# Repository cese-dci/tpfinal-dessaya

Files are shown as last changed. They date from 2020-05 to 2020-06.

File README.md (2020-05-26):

# Teensy 3.2

TP final de la materia Diseño de Circuitos Impresos - CESE - 2020A

Objetivo: Réplica del módulo [Teensy 3.2](https://www.pjrc.com/store/teensy32.html)








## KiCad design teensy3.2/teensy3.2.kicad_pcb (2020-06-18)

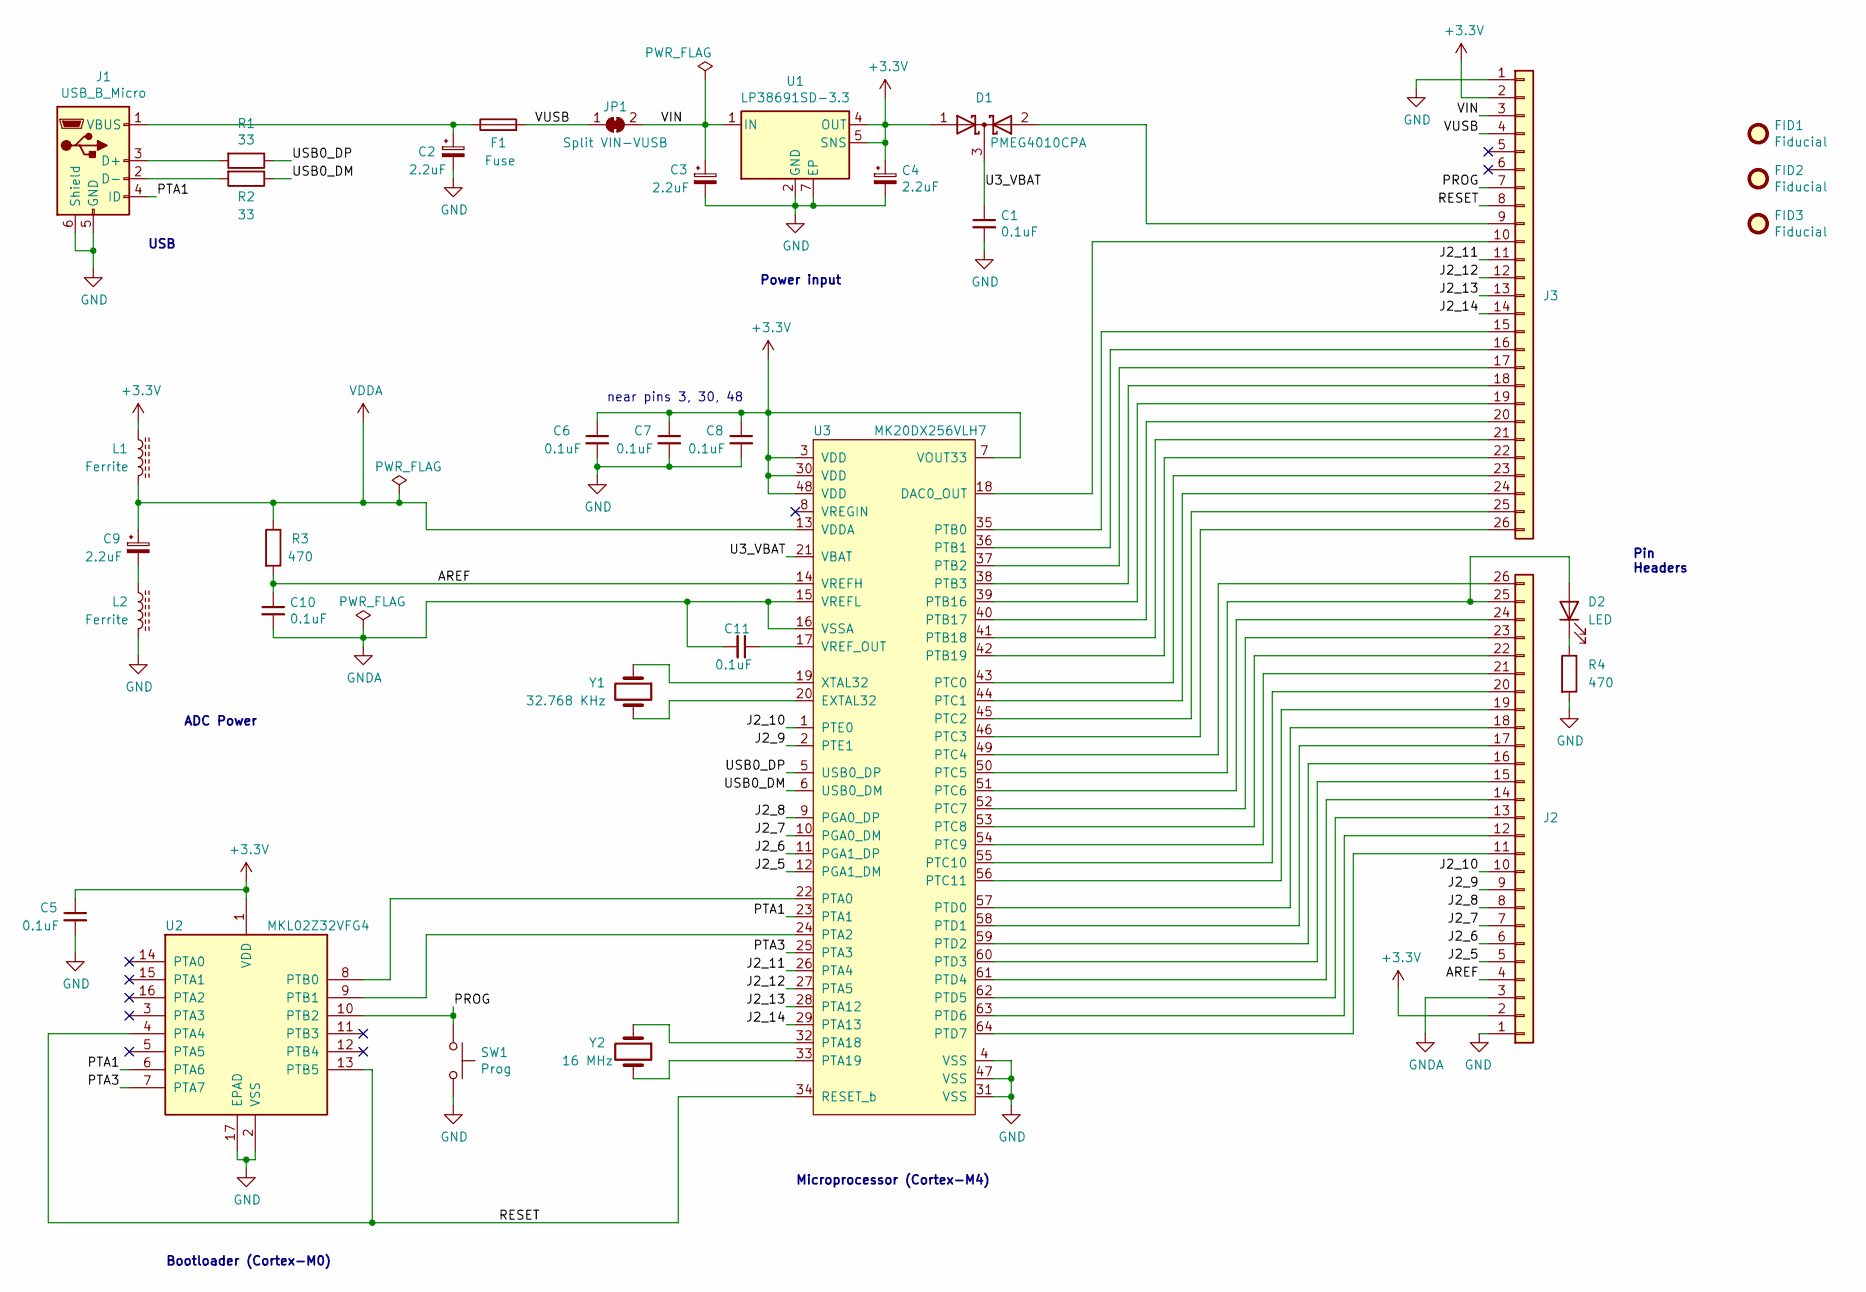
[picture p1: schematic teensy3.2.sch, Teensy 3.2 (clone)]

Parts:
C1, C5, C6, C7, C8, C10, C11: 0.1uF; C_0805_2012Metric
C2, C3, C4, C9: 2.2uF; C_0805_2012Metric
D1: PMEG4010CPA; HUSON-3-1EP_2x2mm_P1.3mm_EP1.1x1.6mm; Digikey# 1727-5212-2-ND
D2: LED; LED_0805_2012Metric
F1: Fuse; Fuse_0805_2012Metric
FID1, FID2, FID3: Fiducial; Fiducial_0.5mm_Mask1.5mm
J1: USB_B_Micro; USB_Micro-B_Molex_47346-0001; Digikey# 2134441-2
J2, J3: Conn_01x26; PinSocket_1x26_P2.54mm_Vertical
JP1: Split VIN-VUSB; SolderJumper-2_P1.3mm_Bridged2Bar_Pad1.0x1.5mm
L1, L2: Ferrite; L_0805_2012Metric; Digikey# 2035-0805CS-331EKFSTR-ND
R1, R2: 33; R_0805_2012Metric
R3, R4: 470; R_0805_2012Metric
SW1: Prog; SW_SPST_PTS810
U1: LP38691SD-3.3; WSON-6-1EP_3x3mm_P0.95mm; Digikey# LP38691SD-3.3/NOPBTR-ND
U2: MKL02Z32VFG4; QFN-16-1EP_3x3mm_P0.5mm_EP1.9x1.9mm; Digikey# MKL02Z32VFG4-ND
U3: MK20DX256VLH7; LQFP-64_10x10mm_P0.5mm; Digikey# MK20DX256VLH7-ND
Y1: 32.768 KHz; Crystal_SMD_2012-2Pin_2.0x1.2mm; Digikey# XC2743CT-ND
Y2: 16 MHz; Crystal_SMD_2016-4Pin_2.0x1.6mm; Digikey# XC2630TR-ND

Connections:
+3V3: C4.1, C5.1, C6.1, C7.1, C8.1, D1.1 (A), J2.2, J3.2, L1.1, U1.4 (OUT), U1.5 (SNS), U2.1 (VDD), U3.3 (VDD), U3.7 (VOUT33), U3.30 (VDD), U3.48 (VDD)
/AREF: C10.1, J2.4, R3.2, U3.14 (VREFH)
/J2_5: J2.5, U3.12 (PGA1_DM)
/J2_6: J2.6, U3.11 (PGA1_DP)
/J2_7: J2.7, U3.10 (PGA0_DM)
/J2_8: J2.8, U3.9 (PGA0_DP)
/J2_9: J2.9, U3.2 (PTE1)
/J2_10: J2.10, U3.1 (PTE0)
/J2_11: J3.11, U3.26 (PTA4)
/J2_12: J3.12, U3.27 (PTA5)
/J2_13: J3.13, U3.28 (PTA12)
/J2_14: J3.14, U3.29 (PTA13)
/PROG: J3.7, SW1.1, U2.10 (PTB2)
/PTA1: J1.4 (ID), U2.6 (PTA6), U3.23 (PTA1)
/PTA3: U2.7 (PTA7), U3.25 (PTA3)
/RESET: J3.8, U2.4 (PTA4), U2.13 (PTB5), U3.34 (RESET_b)
/U3_VBAT: C1.1, D1.3 (K), U3.21 (VBAT)
/USB0_DM: R2.1, U3.6 (USB0_DM)
/USB0_DP: R1.1, U3.5 (USB0_DP)
/VIN: C3.1, J3.3, JP1.2 (B), U1.1 (IN), U1.6 (IN)
/VUSB: F1.2, J3.4, JP1.1 (A)
GND: C1.2, C2.2, C3.2, C4.2, C5.2, C6.2, C7.2, C8.2, J1.5 (GND), J1.6 (Shield), J2.1, J3.1, L2.2, R4.2, SW1.2, U1.2 (GND), U1.7 (EP), U2.2 (VSS), U2.17 (EPAD), U3.4 (VSS), U3.31 (VSS), U3.47 (VSS)
GNDA: C10.2, C11.2, J2.3, U3.15 (VREFL), U3.16 (VSSA)
unnamed: C2.1, F1.1, J1.1 (VBUS)
unnamed: C9.2, L2.1
unnamed: C11.1, U3.17 (VREF_OUT)
unnamed: D1.2 (A), J3.9
unnamed: D2.1 (K), R4.1
unnamed: D2.2 (A), J2.25, U3.50 (PTC5)
unnamed: J1.2 (D-), R2.2
unnamed: J1.3 (D+), R1.2
unnamed: J2.11, U3.64 (PTD7)
unnamed: J2.12, U3.63 (PTD6)
unnamed: J2.13, U3.62 (PTD5)
unnamed: J2.14, U3.61 (PTD4)
unnamed: J2.15, U3.60 (PTD3)
unnamed: J2.16, U3.59 (PTD2)
unnamed: J2.17, U3.58 (PTD1)
unnamed: J2.18, U3.57 (PTD0)
unnamed: J2.19, U3.56 (PTC11)
unnamed: J2.20, U3.55 (PTC10)
unnamed: J2.21, U3.54 (PTC9)
unnamed: J2.22, U3.53 (PTC8)
unnamed: J2.23, U3.52 (PTC7)
unnamed: J2.24, U3.51 (PTC6)
unnamed: J2.26, U3.49 (PTC4)
unnamed: J3.10, U3.18 (DAC0_OUT)
unnamed: J3.15, U3.35 (PTB0)
unnamed: J3.16, U3.36 (PTB1)
unnamed: J3.17, U3.37 (PTB2)
unnamed: J3.18, U3.38 (PTB3)
unnamed: J3.19, U3.39 (PTB16)
unnamed: J3.20, U3.40 (PTB17)
unnamed: J3.21, U3.41 (PTB18)
unnamed: J3.22, U3.42 (PTB19)
unnamed: J3.23, U3.43 (PTC0)
unnamed: J3.24, U3.44 (PTC1)
unnamed: J3.25, U3.45 (PTC2)
unnamed: J3.26, U3.46 (PTC3)
unnamed: U2.8 (PTB0), U3.22 (PTA0)
unnamed: U2.9 (PTB1), U3.24 (PTA2)
unnamed: U3.19 (XTAL32), Y1.1
unnamed: U3.20 (EXTAL32), Y1.2
unnamed: U3.32 (PTA18), Y2.1
unnamed: U3.33 (PTA19), Y2.2
VDDA: C9.1, L1.2, R3.1, U3.13 (VDDA)

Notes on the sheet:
Microprocessor (Cortex-M4)
USB
Bootloader (Cortex-M0)
Power input
ADC Power
near pins 3, 30, 48
Pin Headers

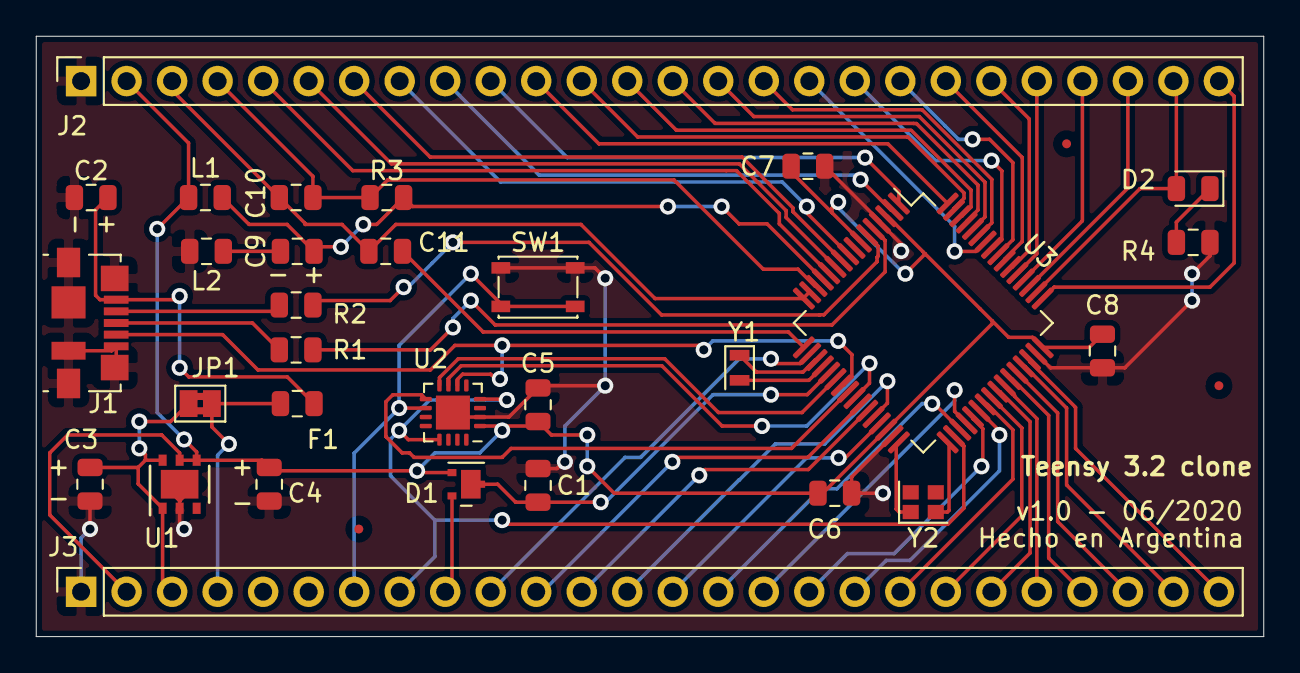
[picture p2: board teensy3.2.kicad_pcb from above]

Board: 2 copper layers, 68.5 x 33.5 mm, 33 parts (0 on the bottom side), 66 nets.

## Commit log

2020-05-26 work in progress
    [teensy3.2.kicad_pcb, teensy3.2.sch]
2020-05-29 ERC ok
    [teensy3.2.sch]
2020-06-05 asignacion de footprints lista
    [teensy3.2.sch]
2020-06-06 PCB wip
    [teensy3.2.kicad_pcb, teensy3.2.sch]
2020-06-08 ajustes al esquematico
    [teensy3.2.sch]
2020-06-11 avances pcb
    [teensy3.2.kicad_pcb, teensy3.2.sch]
2020-06-13 avances sch + pcb
    [teensy3.2.kicad_pcb, teensy3.2.sch]
2020-06-13 avances sch
    [teensy3.2.sch]
2020-06-13 avances ruteo pcb
    [teensy3.2.kicad_pcb]
2020-06-14 fin ruteo pcb
    [teensy3.2.kicad_pcb]
2020-06-14 fin pcb
    [teensy3.2.kicad_pcb]
2020-06-14 ajustes revision pcb
    [teensy3.2.kicad_pcb, teensy3.2.sch]
2020-06-18 ajustes para revision final
    [teensy3.2.kicad_pcb, teensy3.2.sch]

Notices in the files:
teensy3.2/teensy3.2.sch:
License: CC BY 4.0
